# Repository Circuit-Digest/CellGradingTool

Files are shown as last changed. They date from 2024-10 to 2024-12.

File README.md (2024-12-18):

# [CellGradingTool](https://circuitdigest.com/videos/diy-modular-cell-grading-machine)
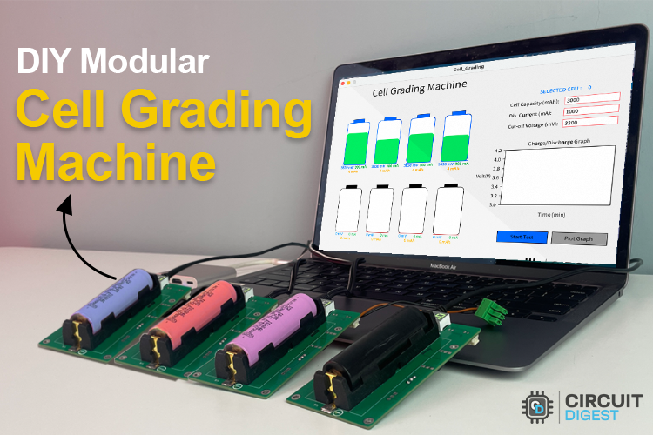
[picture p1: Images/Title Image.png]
image_tooltip

<br>
Testing lithium-ion cells is critical for ensuring their performance, safety, and longevity, particularly in applications such as electric vehicles, energy storage systems, and portable electronics. As these cells can degrade over time, accurate grading tools are necessary to assess their charging, discharging, and overall capacity characteristics. This DIY modular cell grading tool addresses this need by providing a streamlined and scalable solution for testing multiple lithium-ion cells simultaneously while offering precise control over charging and discharging cycles. The tool’s modularity allows users to grade up to 250 cells in parallel, making it a versatile choice for both small and large-scale testing environments. At the heart of the tool is the STM32 G071KBU3 microcontroller, powered by an ADP7118 3.3V LDO regulator. The tool is designed to detect the voltage of each inserted cell and display it on a two-digit seven-segment display, providing instant feedback. When connected to the companion software, users can initiate a test, charging the cell at a constant current of 1A using the TP4056 IC. Upon reaching full charge, the system will disable the charging circuitry and transition into discharge mode, where the discharge current and voltage are monitored through the high-precision INA236 sensor. This setup ensures accurate tracking of both charging and discharging parameters, essential for detailed cell grading.
<br>
Communication between the tool and the PC is managed via the RS485 protocol, utilising the SP485REN transceiver IC. This allows us to connect multiple tools in parallel, with each module being independently controlled by the companion app. The discharge circuit uses an IRF540 MOSFET as a programable DC load and a current control circuit built around the MCP6486 op-amp, ensuring precise current regulation. The DAC output from the STM32G071 is used for adjusting the discharge current, allowing for highly accurate measurements of cell performance under load conditions. The companion software, written in Processing, provides a user-friendly interface for controlling up to 8 modules, with the flexibility to expand to 250 modules. Users can set parameters such as discharge current and voltage limits for each module independently and start tests with a single button click. The software also includes a feature for graphing the discharge voltage curve, providing valuable insights into the cell’s behaviour over time. Even if the cell is removed, the tool retains the test data, ensuring no loss of critical information. With this tool, users can efficiently grade lithium-ion cells and make informed decisions about their suitability for various applications.
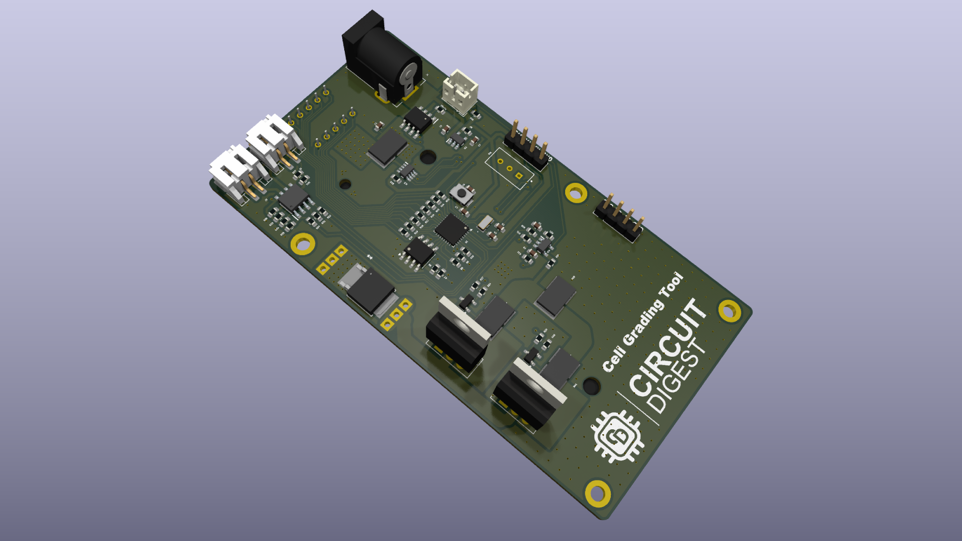
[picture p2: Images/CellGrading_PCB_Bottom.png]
image_tooltip

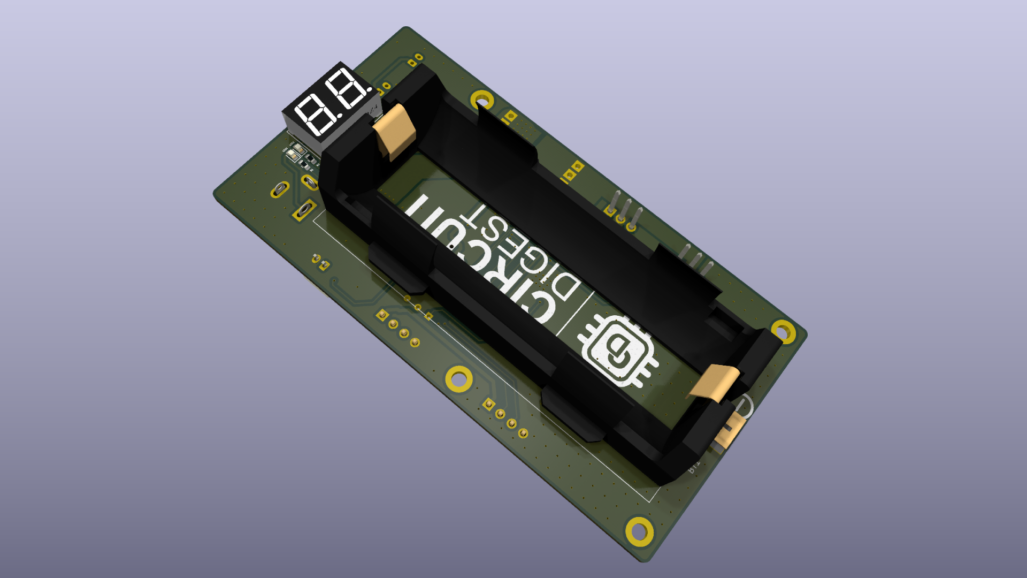
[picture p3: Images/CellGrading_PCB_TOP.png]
image_tooltip

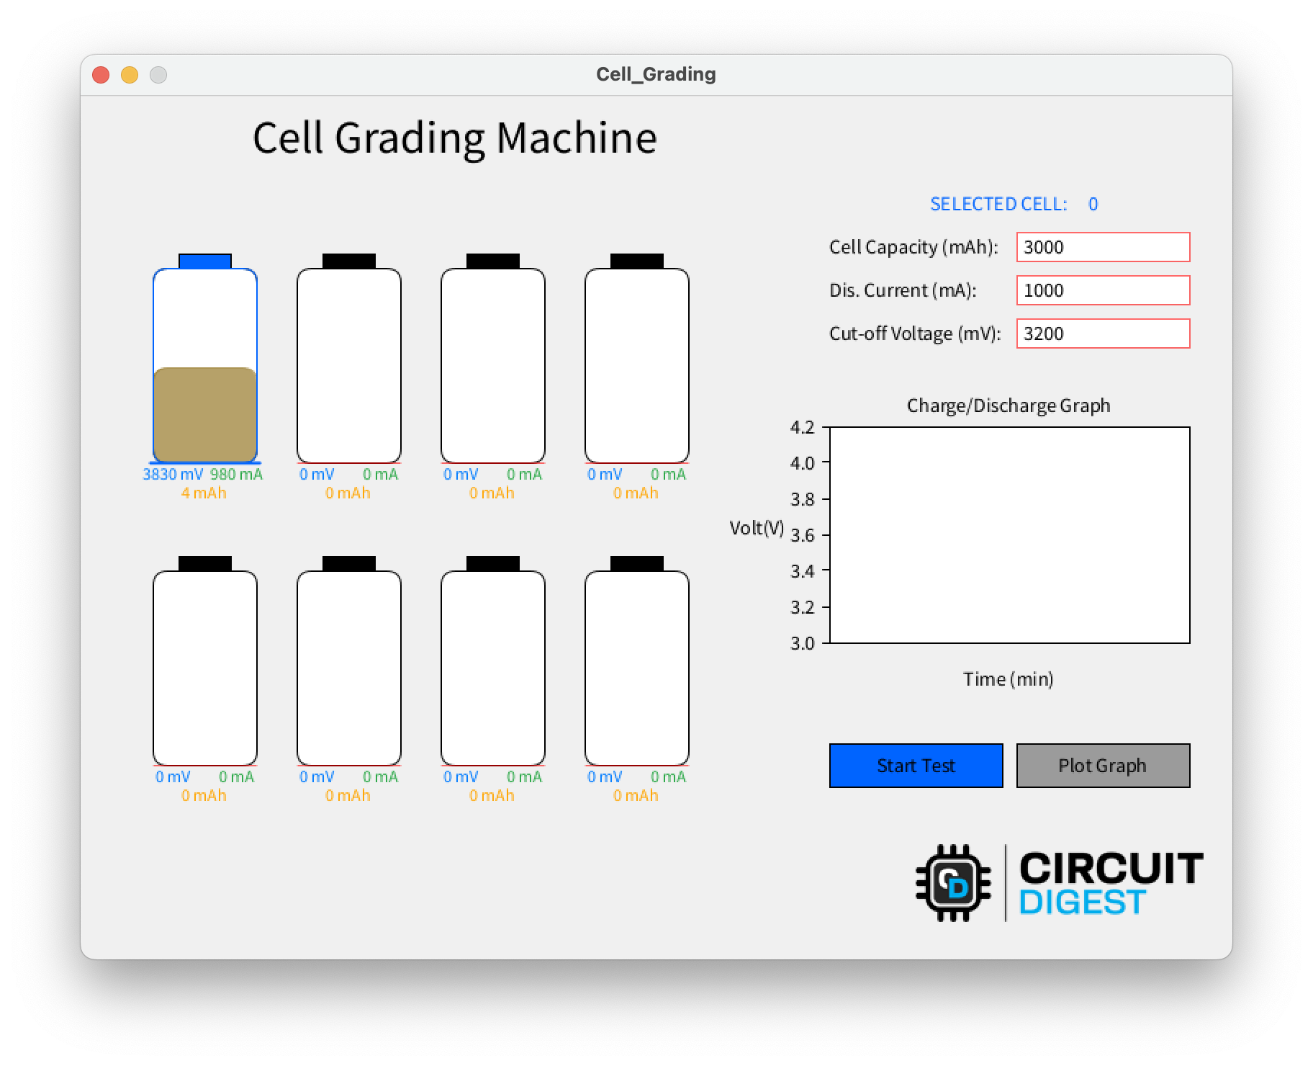
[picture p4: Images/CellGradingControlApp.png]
image_tooltip


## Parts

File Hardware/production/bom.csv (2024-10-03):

Designator | Footprint | Quantity | Value | LCSC Part #
_6, _5, _4, _3, _2, |  | 6
BT1 | BAT_1042 | 1 | Battery_Cell
C1 | 0603 | 1 | 10uF
C2 | 0603 | 1 | 2.2uF
C3 | 0603 | 1 | NC
C4, C5 | 0603 | 2 | 12.5pf
C6 | 0603 | 1 | 0.1uF
C7, C8, C9 | 0603 | 3 | 100n
D1 | TO252_DIO | 1 | SDT30B100D1-13
IC1 | SOIC127P600X175-9N | 1 | TP4056
IC2 | SOT95P280X100-5N | 1 | ADP7118AUJZ-3.3-R7
IC3 | SOT65P280X110-8N | 1 | INA236BIDDFR
IC4 | SOT95P280X145-5N | 1 | MCP6486T-E_OT
IC5 | SOIC127P600X175-8N | 1 | SP485REN-L_TR
J1 | BarrelJack_Kycon_KLDX-0202-xC_Horizontal | 1 | Barrel_Jack_Switch
J2, J3 | JST_PH_S2B-PH-SM4-TB_1x02-1MP_P2.00mm_Horizontal | 2 | Conn_01x02
J4, J5 | PinHeader_1x04_P2.54mm_Vertical | 2 | Conn_01x04
LED1, LED2 | 0603 | 2 | CHG
Q1, Q3 | SOT-23 | 2 | S8050
Q2, Q4 | TO-220-3_Vertical | 2 | IRF540N
R1, R2 | 0603 | 2 | 1.3K
R10, R11, R26, R33, R34, R35, R6, R7 | 0603 | 8 | 10K
R12 | JST_PH_B2B-PH-K_1x02_P2.00mm_Vertical | 1 | NTC
R13, R14, R15, R16, R17, R18, R19, R20, R23, R30, R31, R32, R39, R8, R9 | 0603 | 15 | 1K
R21 | 0603 | 1 | 1K
R22 | 0603 | 1 | 909
R24, R40 | 0603 | 2 | 270K
R25 | 0603 | 1 | 100
R27, R29 | 0603 | 2 | 2.2K
R28, R4, R41 | WSHP2818R0200FEA | 3 | .01 5W
R3 | 0603 | 1 | 0
R36, R37 | 0603 | 2 | 20K
R38 | 0603 | 1 | 120R
R5 | WSHP2818R0200FEA | 1 | 0.01R
RV1 | TRIM_3296W-1-104 | 1 | 200R
Rprog1 | 0603 | 1 | 1.2K
SW1 | Tactile 3x4x2mm TS-A010 | 1 | RST
U1 | QFN-32-1EP_5x5mm_P0.5mm_EP3.45x3.45mm | 1 | STM32G071KBUx
U2 | LTD-2601G_LTO | 1 | LTD-2601G
U3 | SOIC-8_3.9x4.9mm_P1.27mm | 1 | 24CS32
Y1 | ECS327734BCTR | 1 | 32.768KHz

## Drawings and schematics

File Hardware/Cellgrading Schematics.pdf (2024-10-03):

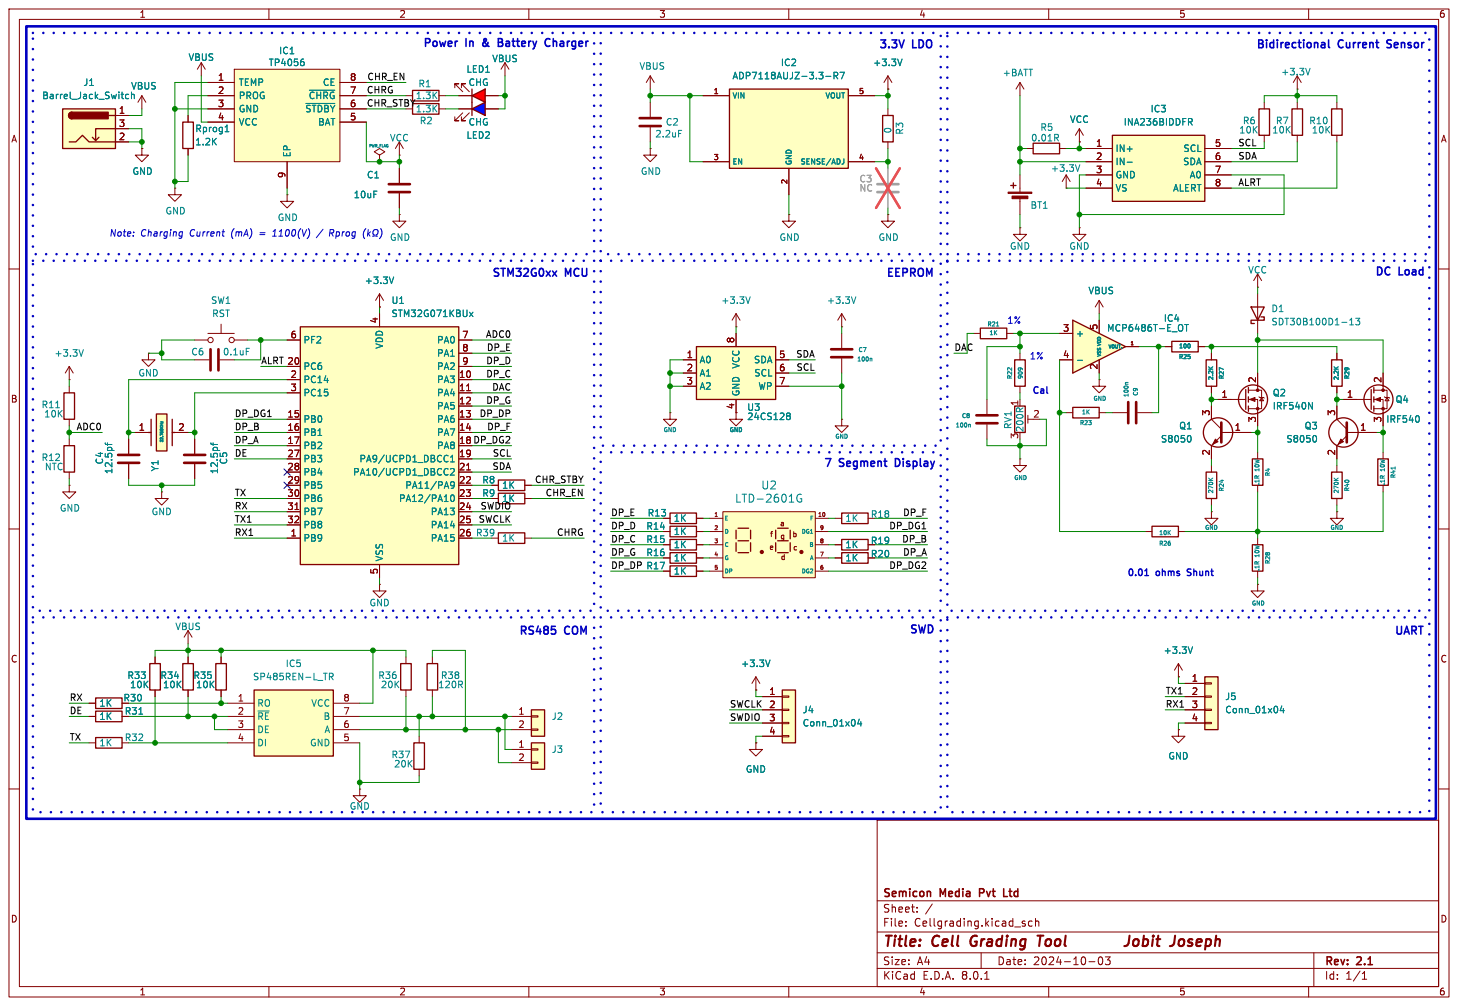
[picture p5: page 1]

2 EN 3 SENSE/ADJ 4 VOUT 5 +3.3V R13 1K

2 EN 3 SENSE/ADJ 4 VOUT 5

UART DC Load SWD
EEPROM

4 SDA 5 SCL 6 WP 7 VCC

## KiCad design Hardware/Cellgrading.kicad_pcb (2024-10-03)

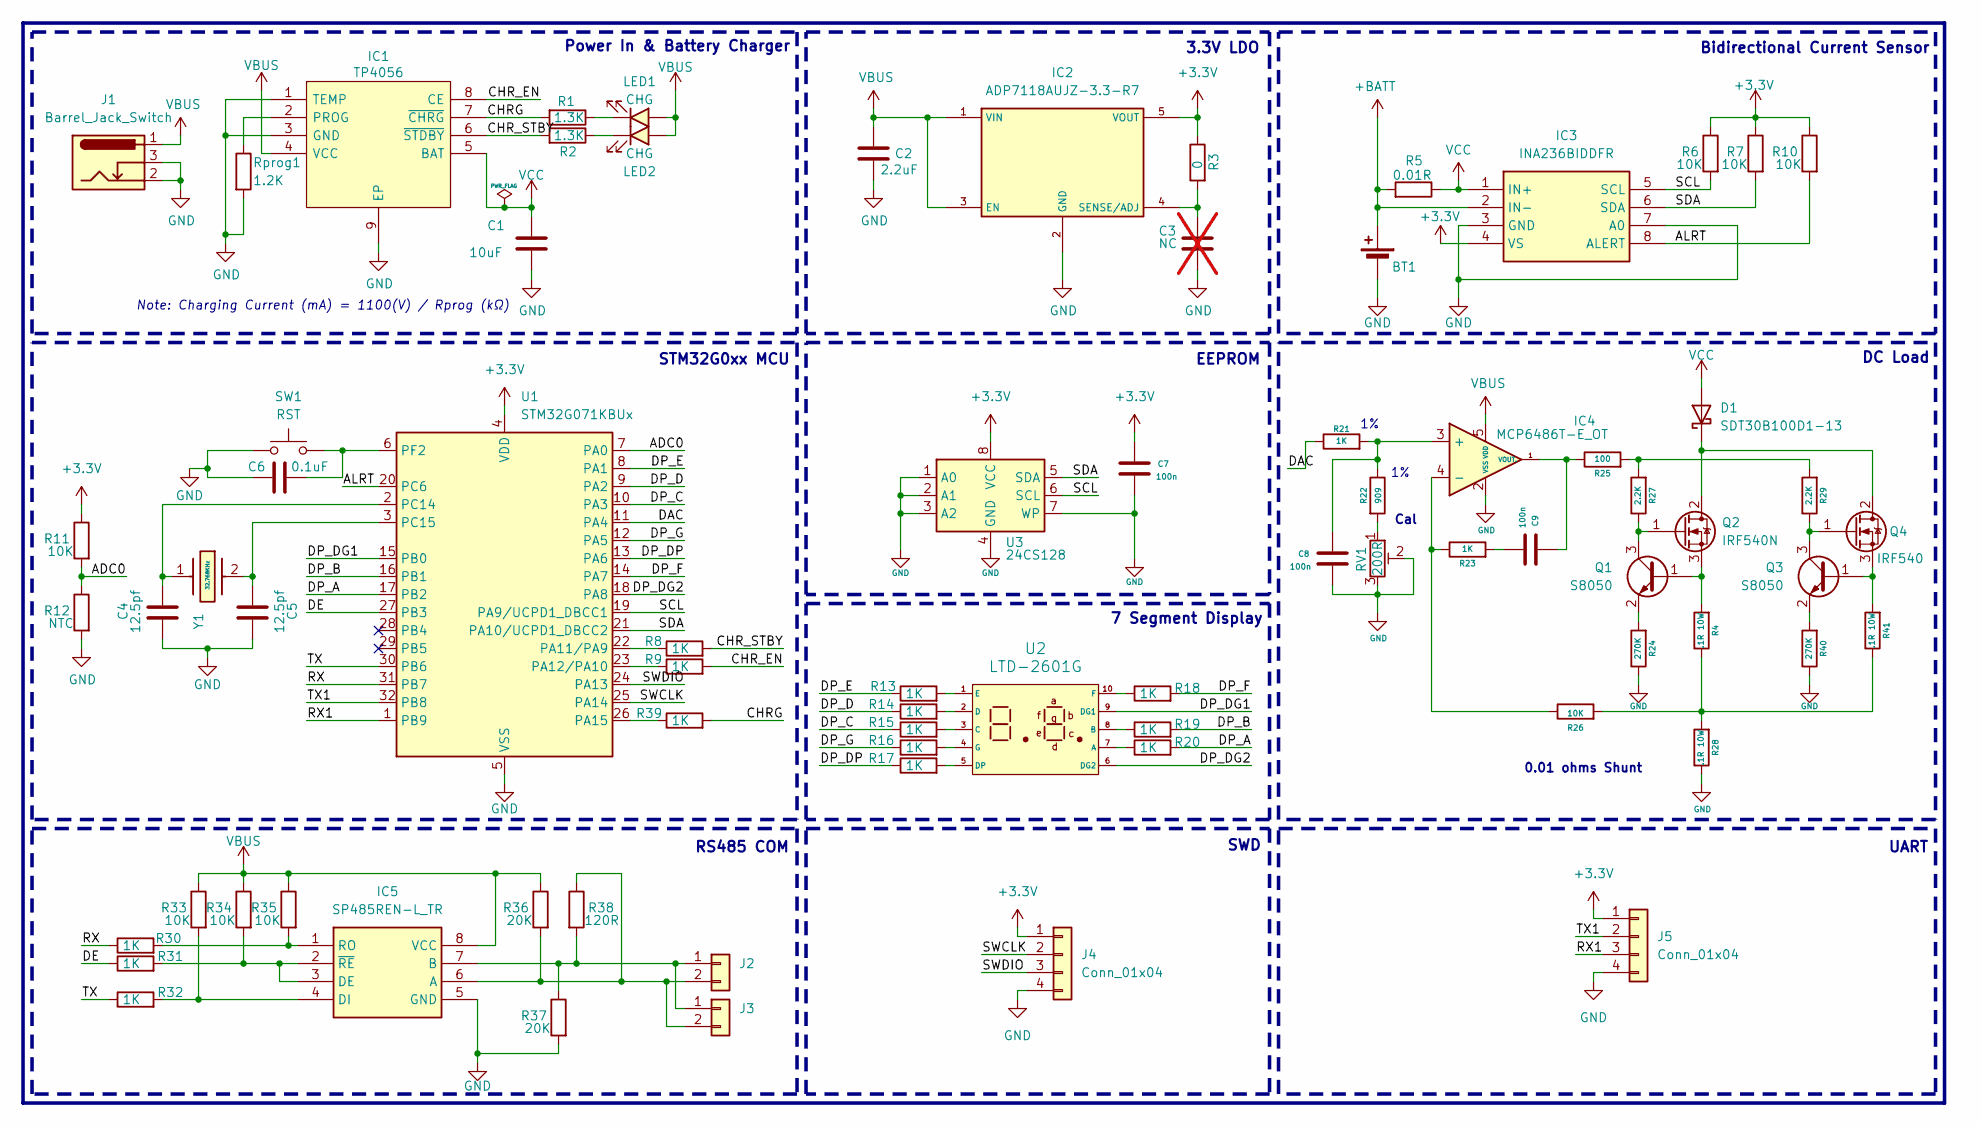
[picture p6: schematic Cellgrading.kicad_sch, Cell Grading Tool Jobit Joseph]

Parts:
BT1: Battery_Cell; BAT_1042
C1: 10uF; C_0603_1608Metric
C2: 2.2uF; C_0603_1608Metric
C3: NC; C_0603_1608Metric; not fitted
C4, C5: 12.5pf; C_0603_1608Metric
C6: 0.1uF; C_0603_1608Metric
C7, C8, C9: 100n; C_0603_1608Metric
D1: SDT30B100D1-13; TO252_DIO
IC1: TP4056; SOIC127P600X175-9N; Manufacturer_Part_Number TP4056-42-ESOP8
IC2: ADP7118AUJZ-3.3-R7; SOT95P280X100-5N; Mouser Part Number 584-ADP7118AUJZ3.3R7
IC3: INA236BIDDFR; SOT65P280X110-8N; Mouser Part Number 595-INA236BIDDFR
IC4: MCP6486T-E_OT; SOT95P280X145-5N; Mouser Part Number 494-MCP6486T-E/OT
IC5: SP485REN-L_TR; SOIC127P600X175-8N; Mouser Part Number 701-SP485REN-L/TR
J1: Barrel_Jack_Switch; BarrelJack_Kycon_KLDX-0202-xC_Horizontal
J2, J3: Conn_01x02; JST_PH_S2B-PH-SM4-TB_1x02-1MP_P2.00mm_Horizontal
J4, J5: Conn_01x04; PinHeader_1x04_P2.54mm_Vertical
LED1, LED2: CHG; LED_0603_1608Metric
Q1, Q3: S8050; SOT-23
Q2: IRF540N; TO-220-3_Vertical
Q4: IRF540; TO-220-3_Vertical
R1, R2: 1.3K; R_0603_1608Metric
R3: 0; R_0603_1608Metric
R4, R28, R41: .1R 10W; WSHP2818R0200FEA
R5: 0.01R; WSHP2818R0200FEA
R6, R7, R10, R11, R26, R33, R34, R35: 10K; R_0603_1608Metric
R8, R9, R13, R14, R15, R16, R17, R18, R19, R20, R21, R23, R30, R31, R32, R39: 1K; R_0603_1608Metric
R12: NTC; JST_PH_B2B-PH-K_1x02_P2.00mm_Vertical
R22: 909; R_0603_1608Metric
R24, R40: 270K; R_0603_1608Metric
R25: 100; R_0603_1608Metric
R27, R29: 2.2K; R_0603_1608Metric
R36, R37: 20K; R_0603_1608Metric
R38: 120R; R_0603_1608Metric
RV1: 200R; TRIM_3296W-1-104
Rprog1: 1.2K; R_0603_1608Metric
SW1: RST; Tactile 3x4x2mm TS-A010
U1: STM32G071KBUx; QFN-32-1EP_5x5mm_P0.5mm_EP3.45x3.45mm
U2: LTD-2601G; LTD-2601G_LTO
U3: 24CS128; SOIC-8_3.9x4.9mm_P1.27mm
Y1: 32.768KHz; ECS327734BCTR; Mouser Part Number 520-ECS-.327-7-34BCT

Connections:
+3.3V: C7.1, IC2.5 (VOUT), IC3.4 (VS), J4.1, J5.1, R3.1, R6.1, R7.1, R10.1, R11.1, U1.4 (VDD), U3.8 (VCC)
+BATT: BT1.1 (+), IC3.2 (IN-), R5.2
/ADC0: R11.2, R12.1, U1.7 (PA0)
/ALRT: IC3.8 (ALERT), R10.2, U1.20 (PC6)
/CHRG: IC1.7 (~CHRG), R1.2, R39.2
/CHR_EN: IC1.8 (CE), R9.2
/CHR_STBY: IC1.6 (~STDBY), R2.2, R8.2
/DAC: R21.1, U1.11 (PA4)
/DE: R31.1, U1.27 (PB3)
/DP_A: R20.2, U1.17 (PB2)
/DP_B: R19.2, U1.16 (PB1)
/DP_C: R15.1, U1.10 (PA3)
/DP_D: R14.1, U1.9 (PA2)
/DP_DG1: U1.15 (PB0), U2.9 (DG1)
/DP_DG2: U1.18 (PA8), U2.6 (DG2)
/DP_DP: R17.1, U1.13 (PA6)
/DP_E: R13.1, U1.8 (PA1)
/DP_F: R18.2, U1.14 (PA7)
/DP_G: R16.1, U1.12 (PA5)
/RX: R30.1, U1.31 (PB7)
/RX1: J5.3, U1.1 (PB9)
/SCL: IC3.5 (SCL), R6.2, U1.19 (PA9/UCPD1_DBCC1), U3.6 (SCL)
/SDA: IC3.6 (SDA), R7.2, U1.21 (PA10/UCPD1_DBCC2), U3.5 (SDA)
/SWCLK: J4.2, U1.25 (PA14)
/SWDIO: J4.3, U1.24 (PA13)
/TX: R32.1, U1.30 (PB6)
/TX1: J5.2, U1.32 (PB8)
GND: BT1.2 (-), C1.2, C2.2, C3.2, C4.2, C5.2, C6.1, C7.2, C8.2, IC1.1 (TEMP), IC1.3 (GND), IC1.9 (EP), IC2.2 (GND), IC3.3 (GND), IC3.7 (A0), IC4.2 (VSS), IC5.5 (GND), J1.2, J1.3, J4.4, J5.4, R12.2, R24.1, R28.1, R37.2, R40.1, RV1.2, RV1.3, Rprog1.2, SW1.1, U1.5 (VSS), U1.33 (VSS), U3.1 (A0), U3.2 (A1), U3.3 (A2), U3.4 (GND), U3.7 (WP)
unnamed: C9.2, R23.2
unnamed: D1.2 (K), Q2.2 (D), Q4.2 (D)
unnamed: IC1.2 (PROG), Rprog1.1
unnamed: C3.1, IC2.4 (SENSE/ADJ), R3.2
unnamed: C8.1, IC4.3 (+), R21.2, R22.1
unnamed: IC4.4 (-), R23.1, R26.1
unnamed: C9.1, IC4.1 (VOUT.), R25.1
unnamed: IC5.6 (A), J2.2, J3.2, R36.2, R38.1
unnamed: IC5.7 (B), J2.1, J3.1, R37.1, R38.2
unnamed: IC5.2 (~RE), IC5.3 (DE), R31.2, R34.2
unnamed: IC5.4 (DI), R32.2, R33.2
unnamed: IC5.1 (RO), R30.2, R35.2
unnamed: LED1.1 (K), R1.1
unnamed: LED2.1 (K), R2.1
unnamed: Q1.1 (B), Q2.3 (S), R4.2
unnamed: Q1.3 (C), Q2.1 (G), R27.1
unnamed: Q1.2 (E), R24.2
unnamed: Q3.1 (B), Q4.3 (S), R41.2
unnamed: Q3.3 (C), Q4.1 (G), R29.1
unnamed: Q3.2 (E), R40.2
unnamed: R22.2, RV1.1
unnamed: R25.2, R27.2, R29.2
unnamed: R4.1, R26.2, R28.2, R41.1
unnamed: R8.1, U1.22 (PA11/PA9)
unnamed: R9.1, U1.23 (PA12/PA10)
unnamed: R39.1, U1.26 (PA15)
unnamed: C4.1, U1.2 (PC14), Y1.1
unnamed: C5.1, U1.3 (PC15), Y1.2 (OUT/IN)
unnamed: C6.2, SW1.2, U1.6 (PF2)
unnamed: R20.1, U2.7 (A)
unnamed: R19.1, U2.8 (B)
unnamed: R15.2, U2.3 (C)
unnamed: R14.2, U2.2 (D)
unnamed: R17.2, U2.5 (DP)
unnamed: R13.2, U2.1 (E)
unnamed: R18.1, U2.10 (F)
unnamed: R16.2, U2.4 (G)
VBUS: C2.1, IC1.4 (VCC), IC2.1 (VIN), IC2.3 (EN), IC4.5 (VDD), IC5.8 (VCC), J1.1, LED1.2 (A), LED2.2 (A), R33.1, R34.1, R35.1, R36.1
VCC: C1.1, D1.1 (A), IC1.5 (BAT), IC3.1 (IN+), R5.1

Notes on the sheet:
EEPROM
7 Segment Display
UART
STM32G0xx MCU
3.3V LDO
Power In & Battery Charger
Cal
SWD
Bidirectional Current Sensor
DC Load
0.01 ohms Shunt
Note: Charging Current (mA) = 1100(V) / Rprog (kΩ)
RS485 COM

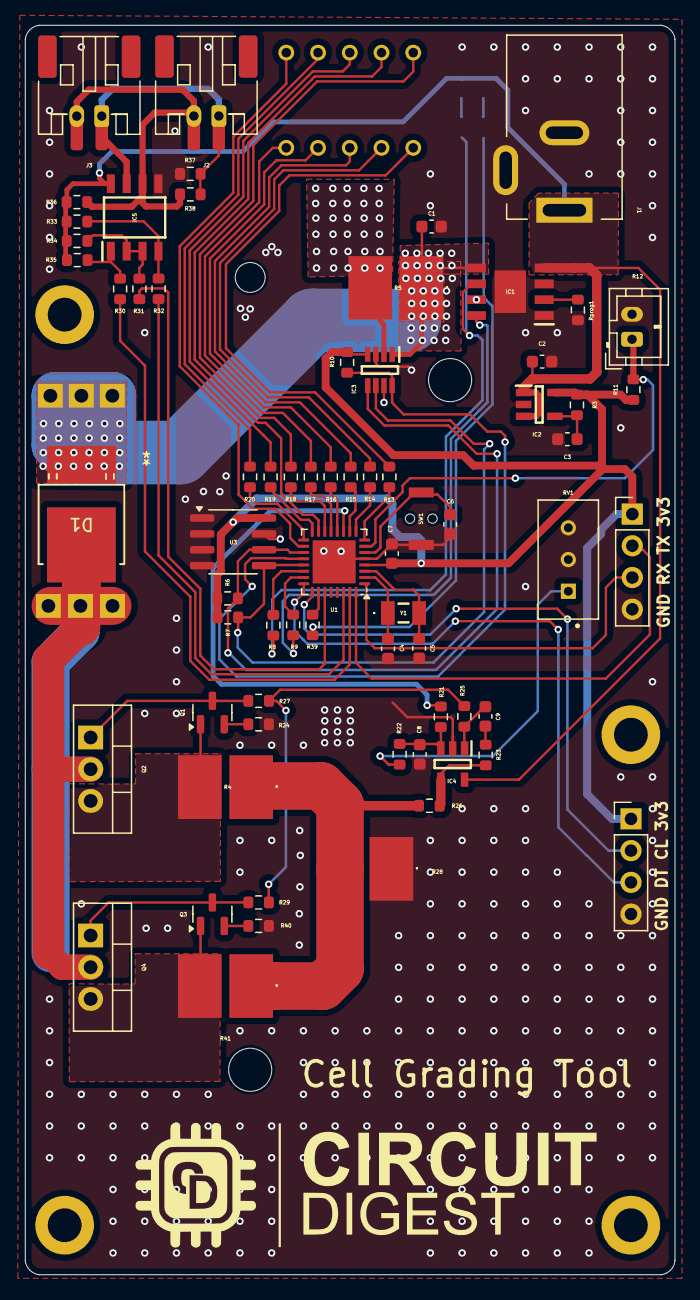
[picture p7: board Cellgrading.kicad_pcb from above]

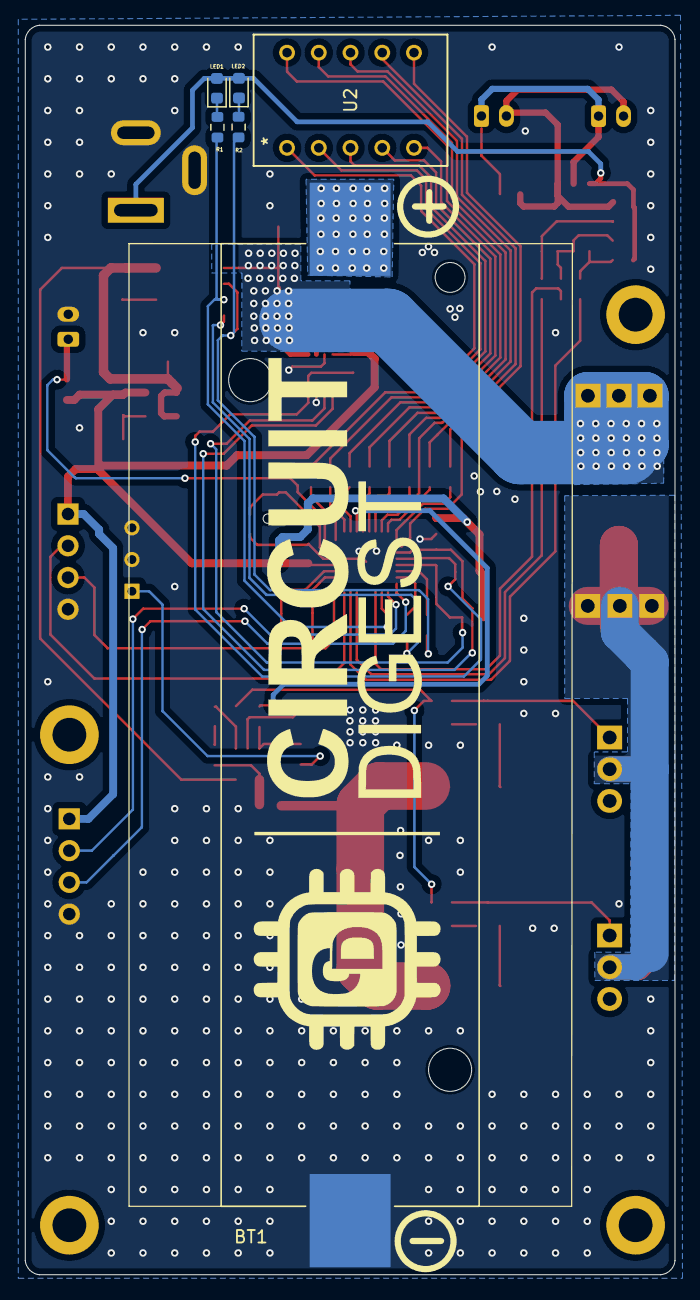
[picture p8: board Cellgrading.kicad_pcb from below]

Board: 2 copper layers, 52.0 x 100.0 mm, 75 parts (6 on the bottom side), 67 nets.

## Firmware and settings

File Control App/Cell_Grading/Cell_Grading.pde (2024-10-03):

/*
 * Project Name: Cell Grading Tool
 * Project Brief: Companion App for Cell Grading Tool
 * Author: Aswinth Raj @ https://github.com/Aswinth-raj
 * IDE: Processing V 4.3
 * Copyright © Aswinth Raj 
 * Copyright © Semicon Media Pvt Ltd
 * Copyright © Circuitdigest.com
 * 
 * This code is licensed under the following conditions:
 *
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
 * 2. Commercial Use:
 * For any commercial use of this software, you must obtain a separate license
 * from the original author. Contact the author for permissions or licensing
 * options before using this software for commercial purposes.
 *
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
 * Author: Aswinth Raj
 * Date: 3 October 2024
 *
 * For commercial use or licensing requests, please contact [contact@circuitdigest.com].
 */

PImage img;
import processing.serial.*;

Serial myPort;  // The serial port
byte[] dischargeCommand = { (byte) 0x00, (byte) 0xD5, (byte) 0x09, (byte) 0xC4, (byte) 0x46 };

byte[] statusCommand = { (byte) 0x00, (byte) 0x51 };
byte[] statusReceived = new byte[7];  // Buffer to store the 7 bytes received
int[] statusData = new int[5];  // Size of 5 based on your data array: cellID, cellStatus, voltage, current, capacity
int[] voltageHistory;  // Declare globally for plotting graph

ArrayList<Byte> historyReceived = new ArrayList<Byte>();
boolean dataAvailable = false;

BatteryCell[] batteries = new BatteryCell[8];  // Array to hold 16 batteries
int selectedCell = -1;  // To track which cell is clicked for displaying graph
int readCell = -1;

String cellCapacity = "";
String dischargeCurrent = "";
String cutoffVoltage = "";
boolean submitted = false;
boolean plot = false;

void setup() {
  
  
  println(dischargeCommand);
  
  statusReceived = new byte[0]; 
  // List all the available serial ports
  println(Serial.list());
  
  // Initialize serial port at baud rate of 115200. Change port index accordingly.
  myPort = new Serial(this, "/dev/tty.usbmodem56580042701", 1000000);
  myPort.clear();
  
  size(800, 600);
  
  img = loadImage("cdlogo.png");
  
  // Initialize battery cells (4 on top and 4 on bottom)
  int count = 0;
  for (int i = 0; i < 4; i++) {
    batteries[count++] = new BatteryCell(100 * i + 50, 120);  // Top row
    batteries[count++] = new BatteryCell(100 * i + 50, 330);  // Bottom row
  }
}

void draw() {
  background(240);
  
  fill(0);
  textSize(32);             // Set font size
  text("Cell Grading Machine", width / 2, 40);  // Centered horizontally, near the top
  image(img, width-220, height-80); //display logo
  
  // Draw each battery
  for (int i = 0; i < batteries.length; i++) {
    batteries[i].display();
  }
  
  // Display data for selected cell
  if (selectedCell != -1) {
    batteries[selectedCell].drawTable();
    batteries[selectedCell].displayGraph();
    batteries[selectedCell].selectionIndicator();

    if(plot)
    batteries[selectedCell].updateGraph();
  }
  
  //Check if we have got history data and plot graph
  if (historyAvailable == true) {
    int validDataSize = historyReceived.size() - 2;
    voltageHistory = new int[validDataSize];
    //display recived voltage
    for (int i = 0; i < validDataSize; i++)
    {
    int rawByte = historyReceived.get(i) & 0xFF;  // Convert to unsigned
    int voltage = ((rawByte + 250) * 10);  // Apply your specific mapping
    voltageHistory[i] = voltage;
    println(voltage);
    }
    
    historyAvailable = false;
    print("End of History Updating");
    statusReceived = new byte[0];  // Clear status buffer for the next message
    statusAvailable = false;
    plot = true;
    
    //while(true);
  }


  
  
  // If status received print that value
  if (statusAvailable == true && historyAvailable == false) {
    statusData = getStatusReceived();
    
    //Update the status in background
    batteries[statusData[0]].updateCharge(statusData[1], statusData[2], statusData[3], statusData[4], (cutoffVoltageInt + 250)*10); //data[0] is cell ID, followed by cellstatus, V, I and capacity
  
    statusAvailable = false;
    statusReceived = new byte[0];  // Clear status buffer for the next message
  }
  
  
  readCell = readCell +1 ;
  //readCell = 0;
  byte[] statusCommand = { (byte) readCell, (byte) 0x51 };
  myPort.write(statusCommand); //write the status command to hardware
  //println("sent status comamnd");
  
  // Print statusCommand as hex values
    StringBuilder hexString = new StringBuilder();
    for (byte b : statusCommand) {
      hexString.append(String.format("%02X ", b));  // Convert byte to 2-digit hex and append to string
    }
  //println("Sent Status Command (Hex): " + hexString.toString().trim());
  
  if (readCell >= 7)
  readCell = -1;
  
}

// Handle key presses to capture input
void keyPressed() {
  if (key == ENTER) {
    submitted = true; // Submit when Enter is pressed
  } else if (key == BACKSPACE) {
    if (focusField == 1) {
      cellCapacity = cellCapacity.length() > 0 ? cellCapacity.substring(0, cellCapacity.length() - 1) : "";
    } else if (focusField == 2) {
      dischargeCurrent = dischargeCurrent.length() > 0 ? dischargeCurrent.substring(0, dischargeCurrent.length() - 1) : "";
    } else if (focusField == 3) {
      cutoffVoltage = cutoffVoltage.length() > 0 ? cutoffVoltage.substring(0, cutoffVoltage.length() - 1) : "";
    }
  } else {
    if (focusField == 1) {
      cellCapacity += key;
    } else if (focusField == 2) {
      dischargeCurrent += key;
    } else if (focusField == 3) {
      cutoffVoltage += key;
    }
  }
}

// Track which input field is focused
int focusField = 0;
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

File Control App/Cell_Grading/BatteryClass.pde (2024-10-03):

// BatteryCell Class
class BatteryCell {
  int cellstatus;
  int voltage;
  int current;
  int capacity;
  int cutoff;
  float x, y, width, height;
  float chargeLevel ;  // Between 0 and 1 representing battery percentage
  boolean charging = false;
  boolean discharging = false;
  
  BatteryCell(float x, float y) {
    this.x = x;
    this.y = y;
    this.width = 72;
    this.height = 135;
    this.chargeLevel = 0.0;  // Start at 0% charge
    this.cellstatus = 0;
    this.voltage = 0;
    this.current = 0;
    this.capacity = 0;
    this.cutoff = 0;
  }
  
  // Display the battery
  void display() {
    stroke(0);
    strokeWeight(1);
    fill(255);
    rect(x, y, width, height, 10);  // Battery body

    // Draw positive terminal
    fill(0);
    rect(x + width * 0.25, y - 10, width * 0.5, 10);
    
    // Display voltage below the battery
    fill(0);
    textSize(12);
    textAlign(CENTER);
    fill(0, 123, 255); text(nf(voltage, 1, 0) + " mV", (x + width / 2)-22, y + height + 12);
    fill(40, 167, 69); text(nf(current, 1, 0) + " mA", (x + width / 2)+22, y + height + 12);
    fill(255, 165, 0); text(nf(capacity, 1, 0) + " mAh", (x + width / 2), y + height + 25);
    
    // Draw the current charge level
    float fillHeight = chargeLevel * height;
    int redValue = int(lerp(255, 0, chargeLevel));  // From 255 (red) to 0 (no red)
    int greenValue = int(lerp(0, 200, chargeLevel));  // From 0 (no green) to 200 (full green)
    stroke(redValue, greenValue, 0, 150);
    fill(redValue, greenValue, 0, 150);
    rect(x, y + height - fillHeight, width, fillHeight, 10);
  }
  
  // Update the charging level and record history
  void updateCharge(int cellstatus, int voltage, int current, int capacity, int cutoff) {
    
    this.cellstatus = cellstatus;
    this.voltage = voltage;
    this.current = current;
    this.capacity = capacity;
    this.cutoff = cutoff;
    
    if (cellstatus == 9) //if cell is idle
    this.voltage = 0;
    
    chargeLevel = map(voltage, cutoff, 4500, 0, 1); 
    if (chargeLevel>1 || chargeLevel<0)
    chargeLevel = 0;
    
    if (cellstatus == 9) //if cell is idle
    {
    this.voltage = 0;
    }
    
    //chargeHistory.add(voltagechargeLevel);
  }
  
  // Check if mouse is over the battery cell
  boolean isMouseOver() {
    return (mouseX > x && mouseX < x + width && mouseY > y && mouseY < y + height);
  }
  
    //Selection Indicator 
  void selectionIndicator() {
    // change positive terminal solor
    fill(0, 100, 255);
    rect(x + width * 0.25, y - 10, width * 0.5, 10);
    noFill();
    stroke(0, 100, 255);
    rect(x, y, width, height, 10);  // Battery body
    
    // Draw a line at the base of the rectangle
    strokeWeight(2); // Thickness of the line
    //stroke(0, 0, 255); // Color of the line (blue)
    line(x-2, y + height, x+2 + width, y + height); // Draw the line across the base
  }
  
  
// Display the charge and discharge graph in the bottom-right corner
void displayGraph() {
  // Define the new position for the graph in the bottom-right corner
  int graphWidth = 250;  // Width of the graph
  int graphHeight = 150; // Height of the graph
  float graphX = 800 - graphWidth - 30;  // X-position, 10 pixels padding from right
  float graphY = 600 - (graphHeight + 220); // Y-position, adjusted for space for buttons
  
  // Draw the graph background
  stroke(0);
  fill(255);
  rect(graphX, graphY, graphWidth, graphHeight);  // Graph background
  
  // Label the graph
  fill(0);
  textAlign(CENTER);
  text("Charge/Discharge Graph", graphX + graphWidth / 2, graphY - 10);  // Title above the graph
  text("Time (min)", graphX + graphWidth / 2, graphY + graphHeight + 30);  // X-axis label below the graph
  textAlign(RIGHT);
  text("Volt(V)", graphX - 30, graphY + graphHeight / 2);  // Y-axis label to the left of the graph
  
  // Draw the X and Y axis ticks and labels
  /*for (int i = 0; i <= 6; i++) {  // X-axis (Time in 20-minute increments)
    float xPos = map(i * 20, 0, 200, graphX, graphX + graphWidth);
    line(xPos, graphY + graphHeight, xPos, graphY + graphHeight + 5);  // Tick mark
    textAlign(CENTER);
    text(i * 20, xPos, graphY + graphHeight + 15);  // Label for time in minutes
  }*/
  
  for (int i = 0; i <= 6; i++) {  // Y-axis (Voltage from 3V to 4.2V)
    float yPos = map(i * 0.2 + 3.0, 3, 4.2, graphY + graphHeight, graphY);
    line(graphX - 5, yPos, graphX, yPos);  // Tick mark
    textAlign(RIGHT);
    text(nf(3.0 + i * 0.2, 1, 1), graphX - 10, yPos + 5);  // Label for voltage in Volts
  }
  
}

void updateGraph(){
    // Define the new position for the graph in the bottom-right corner
    int graphWidth = 250;  // Width of the graph
    int graphHeight = 150; // Height of the graph
    float graphX = 800 - graphWidth - 30;  // X-position, 10 pixels padding from right
    float graphY = 600 - (graphHeight + 220); // Y-position, adjusted for space for buttons
  
    // Draw the graph (charge level over time)
    stroke(0, 0, 255);
    noFill();
    beginShape();
    float closestDistance = Float.MAX_VALUE;
    float closestX = 0;
    float closestY = 0;
    String hoverInfo = "";
  
    for (int i = 0; i < voltageHistory.length; i++) {
        int value = (voltageHistory[i]);  // Voltage value
        
        // Map the X and Y positions to fit inside the graph area
        float timeValue = map(i, 0, voltageHistory.length - 1, 0, graphWidth);  // Time axis (0 to graphWidth)
        
        // Map value to Y-axis (ensuring it stays within graphHeight)
        float yPos = map(value, 3000, 4200, graphY + graphHeight, graphY);  // Y-axis (charge level, flipped)

        // Ensure xPos is correctly mapped
        float xPos = graphX + timeValue;  // X-position

        // Draw the vertex for the graph line
        if (timeValue>0)
        vertex(xPos, yPos);
        
        // Check if the mouse is close to this point
        float distance = dist(mouseX, mouseY, xPos, yPos);
        if (distance < closestDistance) {
            closestDistance = distance;
            closestX = xPos;
            closestY = yPos;
            hoverInfo = "Time: " + i + " min\nVoltage: " + value + " mV";
        }
    }
    endShape();
  
    // If the mouse is hovering near the line, display the voltage and time
    if (closestDistance < 10) {
        fill(0);
        textAlign(LEFT);
        text(hoverInfo, closestX - 100, closestY - 10);  // Show info near the hovered point
    }
    

}

// Function to draw buttons
void drawButton(String label, float x, float y, color btnColor) {
  fill(btnColor);
  stroke(0);
  rect(x, y, 120, 30);  // Button dimensions (120x30)

  // Button label
  fill(0);
  textAlign(CENTER, CENTER);
  text(label, x + 60, y + 15);  // Center text within the button
}
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
